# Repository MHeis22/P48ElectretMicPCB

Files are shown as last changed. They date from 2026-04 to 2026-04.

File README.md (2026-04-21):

Ordered the PCBs from JLCPCB and components from Mouser. Initial test on 26.3.26 provided great results. Noticeably less bass heavy than the Fifine K688 which was used with XLR. Both microphones tested on a Scarlett 2i2 4th generation.

<!-- KICAD_DIFF_GEN_START -->
---
## 🛠 Technical Hardware Summary
*Autogenerated by GitHub Command Center*

### 📋 Project Overview
| Metric | Value |
| :--- | :--- |
| **Board Dimensions** | 37.0 x 51.01 mm |
| **Total Area** | 1887.24 mm² |
| **Layer Count** | 2 Copper Layers |
| **Total Components** | 27 |
| **SMD Components** | 21 |
| **THT Components** | 4 |
| **Unique Parts** | 25 |
| **KiCad Version** | 10.0.1 |

### 📐 Manufacturing & DRC
| Metric | Value |
| :--- | :--- |
| **Vias** | 235 Total (235 TH, 0 Blind, 0 Micro) |

### 📄 Architecture
- **Power Domains:** `GND`

### ⚙️ Mechanical
- **Mounting Holes:** 2 (H2 (MountingHole_2.7mm_M2.5_DIN965_Pad_TopBottom), H1 (MountingHole_2.5mm))

### 🚫 Do Not Populate (DNP)
- J3 (XLR3)

### 🧠 Core ICs & Modules
| Reference | Component | Function / Description |
| :--- | :--- | :--- |
| U1 | [OPA1678](https://octopart.com/search?q=OPA1678IDR&currency=EUR) | Low-Distortion Audio Operational Amplifiers, SOIC-8/VSSOP-8 |

### 🔌 Connectors & Interfaces
| Reference | Type | Component | Description |
| :--- | :--- | :--- | :--- |
| J2 | Connector | [MIC](https://octopart.com/search?q=TBC05-02-1-G-G&currency=EUR) | Generic connector, single row, 01x02, script generated |
| J1 | Connector | [XLR3](https://octopart.com/search?q=TBC05-03-1-G-G&currency=EUR) | Header for XLR pins |
| J3 | Connector | [XLR3](https://octopart.com/search?q=502-C3M&currency=EUR) | XLR Connector, Female, 3 Pins |

### 📏 Passive Components
| Component | Breakdown |
| :--- | :--- |
| Capacitor | 5x0603 and 5xOther |
| Diode | 3xOther |
| Resistor | 9x0603 |

---
<!-- KICAD_DIFF_GEN_END -->

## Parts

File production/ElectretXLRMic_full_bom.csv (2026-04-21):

Qty | Reference | Value | Footprint | Manufacturer_Part_Number | Description
2 | C1, C4 | 3.3uF | Capacitor_THT:C_Rect_L10.3mm_W5.7mm_P7.50mm_MKS4 | R66DD4330AA6AJ | Film Capacitors 63V 3.3 uF 105C 5% 2 Pin LS=7.5 mm AEC-Q200
1 | C2 | 10uF | SamacSys_Parts:CAPAE660X850N | AEH0608100M050R | Aluminium Electrolytic Capacitors - SMD 50V 10uF 5000Hrs 20%
3 | C3, C5, C6 | 100pF | Capacitor_SMD:C_0603_1608Metric_Pad1.08x0.95mm_HandSolder | 0603N101F101CT | Unpolarized capacitor
2 | C9, C10 | 33uF | Capacitor_SMD:C_Elec_8x10.2 | EEE-FK1J330V | Polarized capacitor
2 | D1, D3 | SMAJ58CA | Diode_SMD:D_SMA | 710-824501581 | 400W bidirectional Transient Voltage Suppressor, 58.0Vr, SMA(DO-214AC)
1 | D2 | D_Zener 8.2V | Diode_SMD:D_SOD-123 | BZT52-B8V2_R1_00001 | Zener diode
1 | J1 | XLR3 | Connector_PinHeader_2.54mm:PinHeader_1x03_P2.54mm_Vertical | TBC05-03-1-G-G | Header for XLR pins
1 | J2 | MIC | Connector_PinHeader_2.00mm:PinHeader_1x02_P2.00mm_Vertical | TBC05-02-1-G-G | Generic connector, single row, 01x02, script generated
1 | J3 | XLR3 |  | 502-C3M | XLR Connector, Female, 3 Pins
2 | R1, R2 | 100 | Resistor_SMD:R_0603_1608Metric_Pad0.98x0.95mm_HandSolder | CRT0603ABY-1000ELF | Resistor
1 | R3 | 100k | Resistor_SMD:R_0603_1608Metric_Pad0.98x0.95mm_HandSolder | ERA-3AEB104V | Resistor
2 | R4, R6 | 2.2k | Resistor_SMD:R_0603_1608Metric_Pad0.98x0.95mm_HandSolder | ERA-3AEB222V | Resistor
2 | R5, R7 | 1k | Resistor_SMD:R_0603_1608Metric_Pad0.98x0.95mm_HandSolder | RP0603BRD071KL | Resistor
1 | R8 | 330 | Resistor_SMD:R_0603_1608Metric_Pad0.98x0.95mm_HandSolder | ERA-3AEB331V | Resistor
1 | R9 | 7.5k | Resistor_SMD:R_0603_1608Metric_Pad0.98x0.95mm_HandSolder | ERA-1AEB752C | Resistor
1 | U1 | OPA1678 | Package_SO:SOIC-8_3.9x4.9mm_P1.27mm | OPA1678IDR | Low-Distortion Audio Operational Amplifiers, SOIC-8/VSSOP-8

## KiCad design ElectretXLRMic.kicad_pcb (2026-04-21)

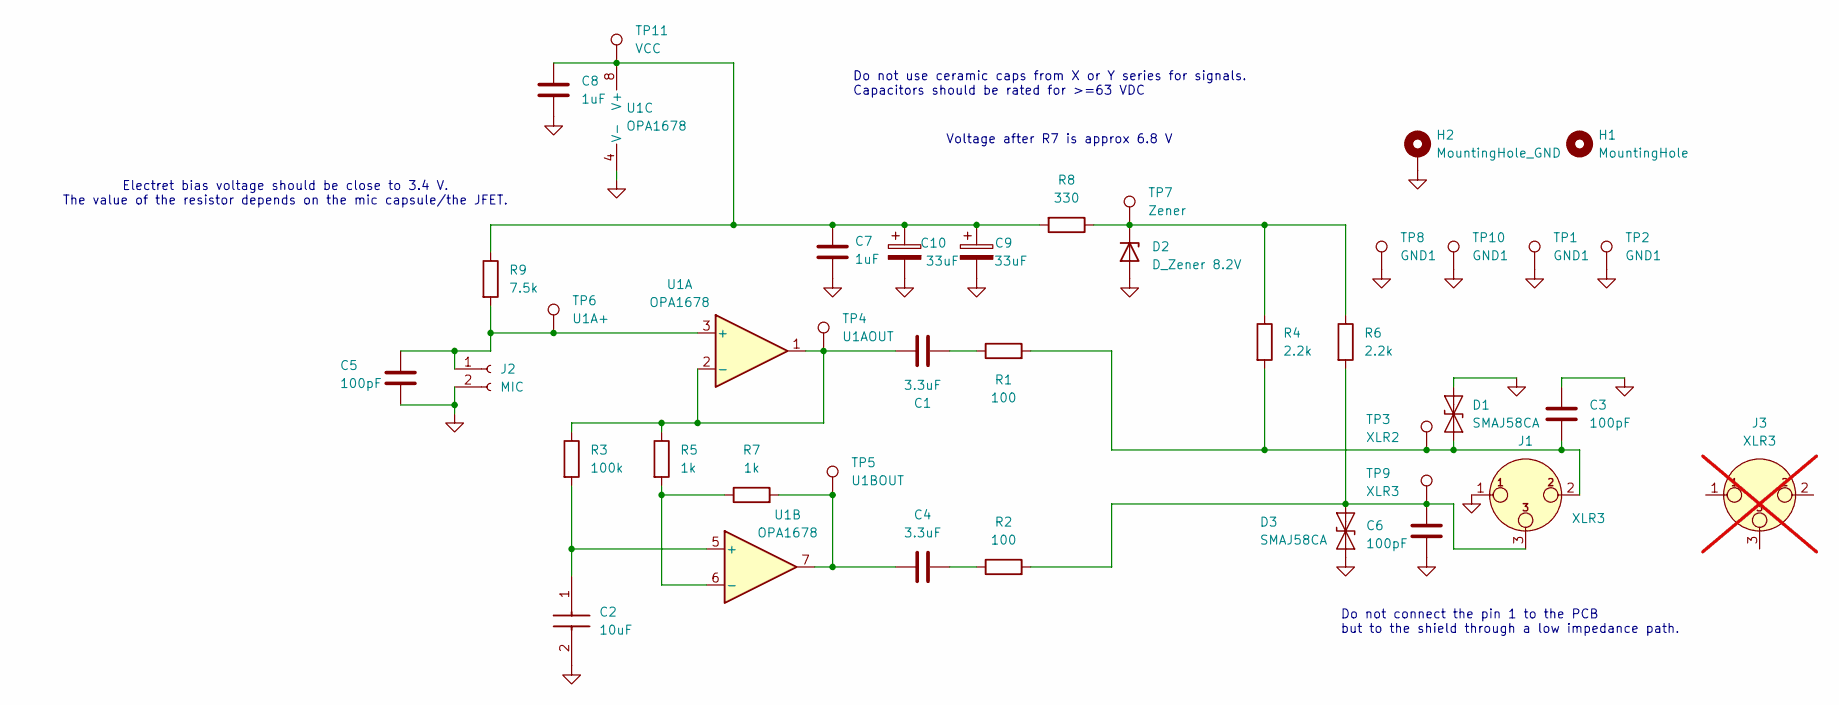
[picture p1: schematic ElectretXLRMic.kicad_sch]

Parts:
C1, C4: 3.3uF; C_Rect_L10.3mm_W5.7mm_P7.50mm_MKS4; Manufacturer_Part_Number R66DD4330AA6AJ
C2: 10uF; CAPAE660X850N; Manufacturer_Part_Number AEH0608100M050R
C3, C5, C6: 100pF; C_0603_1608Metric_Pad1.08x0.95mm_HandSolder; Manufacturer_Part_Number 0603N101F101CT
C7, C8: 1uF; C_0603_1608Metric_Pad1.08x0.95mm_HandSolder
C9, C10: 33uF; C_Elec_8x10.2; Manufacturer_Part_Number EEE-FK1J330V
D1, D3: SMAJ58CA; D_SMA; Manufacturer_Part_Number 710-824501581
D2: D_Zener 8.2V; D_SOD-123; Manufacturer_Part_Number BZT52-B8V2_R1_00001
H1: MountingHole; MountingHole_2.5mm
H2: MountingHole_GND; MountingHole_2.7mm_M2.5_DIN965_Pad_TopBottom
J1: XLR3; PinHeader_1x03_P2.54mm_Vertical; Manufacturer_Part_Number TBC05-03-1-G-G
J2: MIC; PinHeader_1x02_P2.00mm_Vertical; Manufacturer_Part_Number TBC05-02-1-G-G
J3: XLR3; Manufacturer_Part_Number 502-C3M; not fitted
R1, R2: 100; R_0603_1608Metric_Pad0.98x0.95mm_HandSolder; Manufacturer_Part_Number CRT0603ABY-1000ELF
R3: 100k; R_0603_1608Metric_Pad0.98x0.95mm_HandSolder; Manufacturer_Part_Number ERA-3AEB104V
R4, R6: 2.2k; R_0603_1608Metric_Pad0.98x0.95mm_HandSolder; Manufacturer_Part_Number ERA-3AEB222V
R5, R7: 1k; R_0603_1608Metric_Pad0.98x0.95mm_HandSolder; Manufacturer_Part_Number RP0603BRD071KL
R8: 330; R_0603_1608Metric_Pad0.98x0.95mm_HandSolder; Manufacturer_Part_Number ERA-3AEB331V
R9: 7.5k; R_0603_1608Metric_Pad0.98x0.95mm_HandSolder; Manufacturer_Part_Number ERA-1AEB752C
TP1, TP2, TP8, TP10: GND1; TestPoint_Pad_2.0x2.0mm
TP3: XLR2; TestPoint_Pad_2.0x2.0mm
TP4: U1AOUT; TestPoint_Pad_2.0x2.0mm
TP5: U1BOUT; TestPoint_Pad_2.0x2.0mm
TP6: U1A+; TestPoint_Pad_2.0x2.0mm
TP7: Zener; TestPoint_Pad_2.0x2.0mm
TP9: XLR3; TestPoint_Pad_2.0x2.0mm
TP11: VCC; TestPoint_Pad_2.0x2.0mm
U1: OPA1678; SOIC-8_3.9x4.9mm_P1.27mm; Manufacturer_Part_Number OPA1678IDR

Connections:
GND: C2.2 (-), C3.1, C5.2, C6.2, C7.2, C8.2, C9.2, C10.2, D1.2 (A2), D2.2 (A), D3.1 (A1), H2.1 (1_1), J1.1, J2.2, TP1.1 (1_1), TP2.1 (1_1), TP8.1 (1_1), TP10.1 (1_1), U1.4 (V-)
unnamed: C1.1, R1.1
unnamed: C2.1 (+), R3.2, U1.5 (+)
unnamed: C4.1, R7.2, TP5.1 (1_1), U1.7
unnamed: C4.2, R2.1
unnamed: C3.2, D1.1 (A1), J1.2, R1.2, R4.2, TP3.1 (1_1)
unnamed: D2.1 (K), R4.1, R6.1, R8.1, TP7.1 (1_1)
unnamed: C6.1, D3.2 (A2), J1.3, R2.2, R6.2, TP9.1 (1_1)
unnamed: C5.1, J2.1, R9.2, TP6.1 (1_1), U1.3 (+)
unnamed: C1.2, R3.1, R5.1, TP4.1 (1_1), U1.1, U1.2 (-)
unnamed: R5.2, R7.1, U1.6 (-)
unnamed: C7.1, C8.1, C9.1, C10.1, R8.2, R9.1, TP11.1 (1_1), U1.8 (V+)

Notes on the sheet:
Electret bias voltage should be close to 3.4 V. The value of the resistor depends on the mic capsule/the JFET.
Do not use ceramic caps from X or Y series for signals. Capacitors should be rated for >=63 VDC
Do not connect the pin 1 to the PCB but to the shield through a low impedance path.
Voltage after R7 is approx 6.8 V

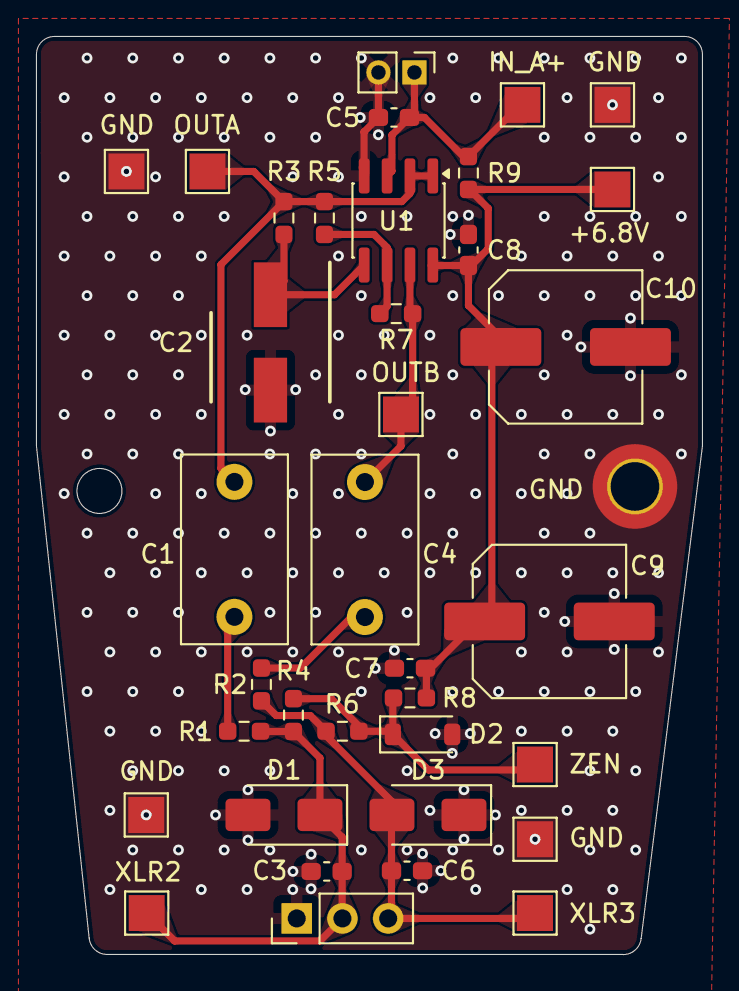
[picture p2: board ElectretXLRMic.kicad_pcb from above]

Board: 2 copper layers, 37.0 x 51.0 mm, 38 parts (0 on the bottom side), 12 nets.

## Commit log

2026-03-13 Add initial note about assembly status
2026-03-15 Slight layout improvements
    [KiCad Version: 9.0.7]
    [ElectretXLRMic.kicad_pcb]
2026-03-16 updated readme
    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
2026-03-16 Readme update
    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
2026-03-16 Readme update/test Slight changes to the schematic
    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
    [ElectretXLRMic.kicad_sch]
2026-03-16 Testing BOM-generator functionality
    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
    [ElectretXLRMic_distributor_bom.csv, ElectretXLRMic_full_bom.csv]
2026-03-16 bom tool update/test
    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
    [ElectretXLRMic_distributor_bom.csv, ElectretXLRMic_full_bom.csv]
2026-03-16 bom check
    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
    [ElectretXLRMic_distributor_bom.csv, ElectretXLRMic_full_bom.csv]
2026-03-16 The TVS diodes had slightly different footprints, fixed now.
    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
    [ElectretXLRMic.kicad_sch, ElectretXLRMic_distributor_bom.csv, ElectretXLRMic_full_bom.csv]
2026-03-16 Test of gerber generator
    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
2026-03-16 Deleting unnecessary files
    [ElectretXLRMic.csv, ElectretXLRMic_distributor_bom.csv, ElectretXLRMic_full_bom.csv]
2026-03-16 Re commit of production files
    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
    [ElectretXLRMic_distributor_bom.csv, ElectretXLRMic_full_bom.csv]
2026-03-17 Cleaned up repo, small changes to PCB layout
    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
    [ElectretXLRMic.kicad_pcb, bom.csv, designators.csv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]
2026-03-17 Updated silkscreen thickness to be in accordance to JLC capabilities (0.153 mm thickness)
    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
    [ElectretXLRMic.kicad_pcb]
2026-03-17 Small changes to the layout
    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
    [ElectretXLRMic.kicad_pcb]
2026-03-25 Test of the circuit is done and final adjustments done for values. BOM has reduced amount of resistors and capacitors. Added 2.54 mm pitch wire terminals to BOM because getting the wires to the conne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
    [ElectretXLRMic.kicad_pcb, ElectretXLRMic.kicad_sch, ElectretXLRMic_distributor_bom.csv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]
2026-03-25 Revise README with testing and sourcing information
    Updated the README with details on PCB and component sourcing, initial testing results, and microphone comparison.
2026-03-25 Added new ibom, removed old.
    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
2026-03-25 readme
    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
2026-04-16 Added teardrops, made board slightly smaller and moved screw holes downwards.
    [KiCad Version: 10.0.1]
    [ElectretXLRMic.kicad_pcb]
2026-04-16 Updated zone fill clearance
    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
    [ElectretXLRMic.kicad_pcb]
2026-04-21 Cleaned up DRC, some routing optimizations, geographical annotation
    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
    [ElectretXLRMic.kicad_pcb, ElectretXLRMic.kicad_sch, ElectretXLRMic_distributor_bom.csv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]
